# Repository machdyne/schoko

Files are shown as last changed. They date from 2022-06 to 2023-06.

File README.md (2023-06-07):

# Schoko Computer

Schoko is an FPGA computer designed by Lone Dynamics Corporation.

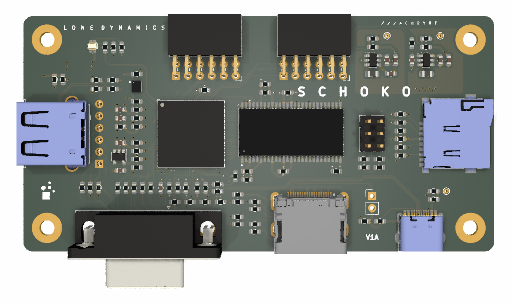
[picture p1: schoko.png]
Schoko Computer


This repo contains schematics, pinouts, a 3D-printable case, example gateware and documentation.

Find more information on the [Schoko product page](https://machdyne.com/product/schoko-computer/).

## Programming Schoko

Schoko has a JTAG interface and ships with a [DFU bootloader](https://github.com/machdyne/tinydfu-bootloader) that allows the included flash [MMOD](https://machdyne.com/product/mmod) to be programmed over the USB-C port.

The first 1MB of the flash MMOD is reserved for the bootloader, the next 3MB are reserved for user gateware and the remaining space is available for user data.

### DFU

The DFU bootloader is available for 5 seconds after power-on, issuing a DFU command during this period will stop the boot process until the DFU device is detached. If no command is received the boot process will continue and the user gateware will be loaded.

Install [dfu-util](http://dfu-util.sourceforge.net) (Debian/Ubuntu):

```
$ sudo apt install dfu-util
```

Update the user gateware on the flash MMOD:

```
$ sudo dfu-util -a 0 -D image.bit
```

Detach the DFU device and continue the boot process:

```
$ sudo dfu-util -a 0 -e
```

It is possible to update the bootloader itself using DFU but you shouldn't attempt this unless you have a JTAG programmer (or another method to program the MMOD) available, in case you need to restore the bootloader.

### JTAG

These examples assume you're using a "USB Blaster" JTAG cable, see the header pinout below. You will need to have [openFPGALoader](https://github.com/trabucayre/openFPGALoader) installed.

Program the configuration SRAM:

```
openFPGALoader -c usb-blaster image.bit
```

Program the flash MMOD:

```
openFPGALoader -f -c usb-blaster images/bootloader/tinydfu_schoko.bit
```

## Blinky 

Building the blinky example requires [Yosys](https://github.com/YosysHQ/yosys), [nextpnr-ecp5](https://github.com/YosysHQ/nextpnr) and [Project Trellis](https://github.com/YosysHQ/prjtrellis).

Assuming they are installed, you can simply type `make` to build the gateware, which will be written to output/blinky.bin. You can then use [openFPGALoader](https://github.com/trabucayre/openFPGALoader) or dfu-util to write the gateware to the device.

## Linux

See the [Kakao Linux](https://github.com/machdyne/kakao) repo for the latest instructions.

### Prebuilt Images

Copy the files from the `images/linux` directory to the root directory of a FAT-formatted MicroSD card.

Schoko ships with LiteX gateware on the user gateware section of the MMOD that is compatible with these images. If you plug a USB-UART into PMODA you should be able to interact with LiteX and view the Linux boot messages. After several seconds the Linux penguin should appear on the screen (HDMI) followed by a login prompt.

You can switch to the VGA gateware with:
 
```
$ sudo dfu-util -a 0 -D images/v1_vga/schoko.bit
```

Note: It should be possible to store the Linux images on the MMOD itself and boot Linux without any MicroSD card but this is not yet supported.

### Building Linux

Please follow the setup instructions in the [linux-on-litex-vexriscv](https://github.com/litex-hub/linux-on-litex-vexriscv) repo and then:

1. Build the Linux-capable gateware:

```
$ cd linux-on-litex-vexriscv
$ ./make.py --board schoko --uart-baudrate 1000000 --build
$ ls build/schoko
```

2. Write the gateware to the MMOD using USB DFU:

```
$ sudo dfu-util -a 0 -D build/schoko/gateware/schoko.bit
```

3. Copy the device tree binary `build/schoko/schoko.dtb` to a FAT-formatted MicroSD card.

4. Build the Linux kernel and root filesystem:

```
$ cd ..
$ git clone http://github.com/buildroot/buildroot
$ cd buildroot
$ make BR2_EXTERNAL=../linux-on-litex-vexriscv/buildroot/ litex_vexriscv_usbhost_defconfig
```

Optionally customize the kernel and buildroot packages:

```
$ make menuconfig
```

Build the kernel and rootfs:

```
$ make
$ ls output/images
```

5. Copy the `Image` and `rootfs.cpio` files from output/images to the MicroSD card.

6. Copy the OpenSBI binary (included in this repo as `schoko/images/linux/opensbi.bin`) to the MicroSD card. Alternatively, you can build this binary by following [these instructions](https://github.com/litex-hub/linux-on-litex-vexriscv#-generating-the-opensbi-binary-optional).

7. Copy `schoko/images/linux/boot.json` to the MicroSD card.

8. Power-cycle Schoko and if a USB-UART PMOD is attached to PMODA you should see the LiteX memory test and then the Linux boot messages. After Linux has finished booting you should see a login prompt on the serial console and the HDMI display.

## LiteX

### Installing LiteX

If you haven't yet installed LiteX please see the [LiteX quick start guide](https://github.com/enjoy-digital/litex#quick-start-guide) for details on installing LiteX.

### Building Custom Gateware

Build the LiteX gateware:

```
$ cd litex-boards/litex_boards/targets
$ ./machdyne_schoko.py --cpu-type=vexriscv --cpu-variant=lite --sys-clk-freq 40000000 --uart-baudrate 1000000 --uart-name serial --build
```

Program the LiteX gateware to SRAM over JTAG:

```
$ ./machdyne_schoko.py --cable usb-blaster --load
```

Or program the LiteX gateware to flash over DFU:

```
$ sudo dfu-util -a 0 -D build/machdyne_schoko/gateware/machdyne_schoko.bit
```

## JTAG Header

The JTAG header can be used to program the FPGA SRAM as well as the MMOD flash memory. 

```
1 2
3 4
5 6
```

| Pin | Signal |
| --- | --- |
| 1 | TCK |
| 2 | TDI |
| 3 | TDO |
| 4 | TMS |
| 5 | 3V3 |
| 6 | GND |

## Board Revisions

| Revision | Notes |
| --- | ----- |
| V0 | Internal prototype |
| V1 | Initial production boards |
| V1A | Identical to V1 except for minor aesthetic changes on the silkscreen |
| V2 | Work-in-progress; adds SD-mode for MicroSD card |

## License

The contents of this repo are released under the [Lone Dynamics Open License](LICENSE.md) with the following exceptions:

- The KiCad design files contain parts of the [kicad-pmod](https://github.com/mithro/kicad-pmod) library which is released under the [Apache License, Version 2.0](https://www.apache.org/licenses/LICENSE-2.0.html).

- The KiCad design files may contain symbols and footprints released under other licenses; please contact us if we've failed to give proper attribution.

Note: You can use these designs for commercial purposes but we ask that instead of producing exact clones, that you either replace our trademarks and logos with your own or add your own next to ours.

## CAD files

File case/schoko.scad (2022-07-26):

/*
 * Schoko Case
 * Copyright (c) 2022 Lone Dynamics Corporation. All rights reserved.
 *
 */

$fn = 100;

mach_edition = false;
schoko_text = true;

board_width = 50;
board_thickness = 1.5;
board_length = 100;
board_height = 20;
board_spacing = 2;

ldx_board();

translate([0,0,15])
	ldx_case_top();

translate([0,0,-15])
	ldx_case_bottom();

module ldx_board() {
	
	difference() {
		color([0,0.5,0])
			roundedcube(board_width,board_length,board_thickness,3);
		translate([5, 5, -1]) cylinder(d=3.2, h=10);
		translate([5, 95, -1]) cylinder(d=3.2, h=10);
		translate([45, 5, -1]) cylinder(d=3.2, h=10);
		translate([45, 95, -1]) cylinder(d=3.2, h=10);
	}	
	
}

module ldx_case_top() {

	union() {
	
		// support between pmods
		translate([0,50-3.5,0])
				cube([5,7.5,14.5]);

		// support above usb host port
		if (mach_edition) {
			translate([25-(14.5/2),-1,7.5]) cube([14.5,10,8.5]);
		} else {
			translate([25-(14.5/2),0,7.5]) cube([14.5,10,7.5]);
		}
		
		difference() {

			union () {
			
				color([0.5,0.5,0.5])
					roundedcube(board_width,board_length,15,3);

				if (mach_edition) {
					translate([-1,board_length-15+1,6])
						cube([board_width+2,4,10]);
					translate([-1,board_length-20+1,6])
						cube([board_width+2,4,10]);
					translate([-1,board_length-25+1,6])
						cube([board_width+2,4,10]);
				}
			
			}
	
			translate([1.5,2,-2.8])
				roundedcube(board_width-3,board_length-4,6,3);

			translate([1.5,10,-2])
				roundedcube(board_width-8,board_length-63.7,15,3);

			translate([10.5,2,-2])
				roundedcube(board_width-21.5,board_length-4,15,5);

			// vent
			translate([-1,board_length-15,10])
				cube([(board_width/2)-8,1,8]);		
			translate([(board_width/2)+8,board_length-15,10])
				cube([(board_width/2)-8,1,8]);

			translate([-1,board_length-20,10])
				cube([(board_width/2)-8,1,8]);		
			translate([(board_width/2)+8,board_length-20,10])
				cube([(board_width/2)-8,1,8]);

			if (!mach_edition) {

				translate([-1,board_length-25,10])
					cube([(board_width/2)-8,1,8]);		
				translate([(board_width/2)+8,board_length-25,10])
					cube([(board_width/2)-8,1,8]);
			
			}

			// LED vent
			translate([-1,board_length-80,5])
				cube([board_width-10,2,2]);

			translate([-1,board_length-85,5])
				cube([board_width-10,2,2]);

			translate([-1,board_length-90,5])
				cube([board_width-10,2,2]);
		
			// VGA
			translate([30,26.23-(31/2),-2]) cube([30,31,12.5+2]);

			// DDMI
			translate([30,60.8-(16/2),-2]) cube([30,15.5,6+2]);

			// USBC
			translate([30,84.3-(10.5/2),-2]) cube([30,10,3.5+1.75]);

			// USBA HOST
			translate([25-(14.5/2),-2,-2]) cube([14.5,30,7.5+2]);
		
			// SD
			translate([25-(15/2),90,-2]) cube([15,30,2+2]);

			// SD resistor cutouts
			translate([8,74,-2]) cube([15,10,2+2]);
			translate([17,74,-2]) cube([15,10,2+2]);

			// PMODA
			translate([0,45.095-(13.05/2),0]) cube([25,16,10],center=true);

			// PMODB
			translate([0,67.955-(13.05/2),0]) cube([25,16,10], center=true);
		
			// bolt holes
			translate([5, 5, -21]) cylinder(d=3.5, h=40);
			translate([5, 95, -21]) cylinder(d=3.5, h=40);
			translate([45, 5, -20]) cylinder(d=3.5, h=40);
			translate([45, 95, -21]) cylinder(d=3.5, h=40);

			// flush mount bolt holes
			translate([5, 5, 14]) cylinder(d=5, h=4);
			translate([5, 95, 14]) cylinder(d=5, h=4);
			translate([45, 5, 14]) cylinder(d=5, h=4);
			translate([45, 95, 14]) cylinder(d=5, h=4);

			// schoko text
			if (schoko_text) {
				rotate(270)
					translate([-40,25-3,14])
						linear_extrude(5)
							text("S C H O K O", size=6, halign="center",
								font="Ubuntu:style=Bold");
			}

		}	
	
	}

}

module ldx_case_bottom() {
	
	difference() {
		color([0.5,0.5,0.5])
			roundedcube(board_width,board_length,8.5,3);
		
		translate([2,10,2])
			roundedcube(board_width-4,board_length-20,8,3);
				
		translate([10,2.5,2])
			roundedcube(board_width-20,board_length-5,8,3);

		// bolt holes
		translate([5, 5, -11]) cylinder(d=3.2, h=25);
		translate([5, 95, -11]) cylinder(d=3.2, h=25);
		translate([45, 5, -11]) cylinder(d=3.2, h=25);
		translate([45, 95, -11]) cylinder(d=3.2, h=25);

		// nut holes
		translate([5, 5, -1.5]) cylinder(d=7, h=4.5, $fn=6);
		translate([5, 95, -1.5]) cylinder(d=7, h=4.5, $fn=6);
		translate([45, 5, -1.5]) cylinder(d=7, h=4.5, $fn=6);
		translate([45, 95, -1.5]) cylinder(d=7, h=4.5, $fn=6);

	}	
}

// https://gist.github.com/tinkerology/ae257c5340a33ee2f149ff3ae97d9826
module roundedcube(xx, yy, height, radius)
{
    translate([0,0,height/2])
    hull()
    {
        translate([radius,radius,0])
        cylinder(height,radius,radius,true);

        translate([xx-radius,radius,0])
        cylinder(height,radius,radius,true);

        translate([xx-radius,yy-radius,0])
        cylinder(height,radius,radius,true);

        translate([radius,yy-radius,0])
        cylinder(height,radius,radius,true);
    }
}

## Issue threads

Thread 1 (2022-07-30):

Source code for the VGA bit stream

wdevore, 2022-07-30:
Is the HDL source code available and more importantly a complete PCF file? Thanks.

machdyne, 2022-07-30:
I've updated the [schoko_v1.lpf](https://github.com/machdyne/schoko/blob/main/schoko_v1.lpf) file, it should now be complete. It was partially generated by LiteX from this file:

[litex_boards/platforms/machdyne_schoko.py](https://github.com/litex-hub/litex-boards/blob/master/litex_boards/platforms/machdyne_schoko.py)

The `images/v1_vga/schoko.bit` bitstream was generated by [linux-on-litex-vexriscv](https://github.com/litex-hub/linux-on-litex-vexriscv) after enabling the "VGA Framebuffer" and disabling the "DDMI Framebuffer" section in this file:

[litex_boards/targets/machdyne_schoko.py](https://github.com/litex-hub/litex-boards/blob/master/litex_boards/targets/machdyne_schoko.py)

If you want to customize/build the bitstream yourself there are some instructions for [Building Linux](https://github.com/machdyne/schoko#building-linux).

There's also [instructions for using LiteX](https://github.com/machdyne/schoko#litex) to build simpler gateware if you don't want to run Linux but still want the LiteX CPUs, SDRAM controller, framebuffer, etc.

We don't have any non-LiteX examples so far beyond the blinky in this repo.

wdevore, 2022-07-30:
Okay, cool. I'll checkout the .lpf file, although I'm not that familiar with .lpf files. How similar are they to .pcf?

machdyne, 2022-07-30:
The purpose is similar but LPF has different syntax and options for ECP5.

There's bit more detail here:

https://github.com/YosysHQ/nextpnr/blob/master/docs/constraints.md

wdevore, 2022-07-30:
Excellent, thanks.

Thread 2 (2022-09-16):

About the USB host

regymm, 2022-09-16:
Hi, the board looks interesting!

I'm curious how does the USB host work? For the other USB port, it seems a USB device is implemented in FPGA fabric(as in the DFU repo), but I didn't find any explanation about the USB host. Is there any demo code or so here or on Litex?

machdyne, 2022-09-16:
Hi. The USB host controller is also implemented in FPGA fabric.

There is a USB OHCI included in LiteX as [usb_ohci.py](https://github.com/enjoy-digital/litex/blob/master/litex/soc/cores/usb_ohci.py) that is [from SpinalHDL](https://spinalhdl.github.io/SpinalDoc-RTD/dev/SpinalHDL/Libraries/Com/usb_ohci.html).

You can see where it's used by Schoko [here](https://github.com/litex-hub/litex-boards/blob/master/litex_boards/targets/machdyne_schoko.py#L132).

USB host support is automatically enabled when building [linux-on-litex-riscv](https://github.com/litex-hub/linux-on-litex-vexriscv) for Schoko.

I've successfully tested a USB keyboard, USB ethernet and USB flash drives with Schoko from Linux.

There does seem to be some issues when using multiple devices through the USB hubs that I've tried. I haven't been able to debug that yet but hopefully it will be resolved eventually.

regymm, 2022-09-16:
Thanks for your quick reply. It's amazing to see USB host works well on 2 wires.

Closed 2022-09-16.

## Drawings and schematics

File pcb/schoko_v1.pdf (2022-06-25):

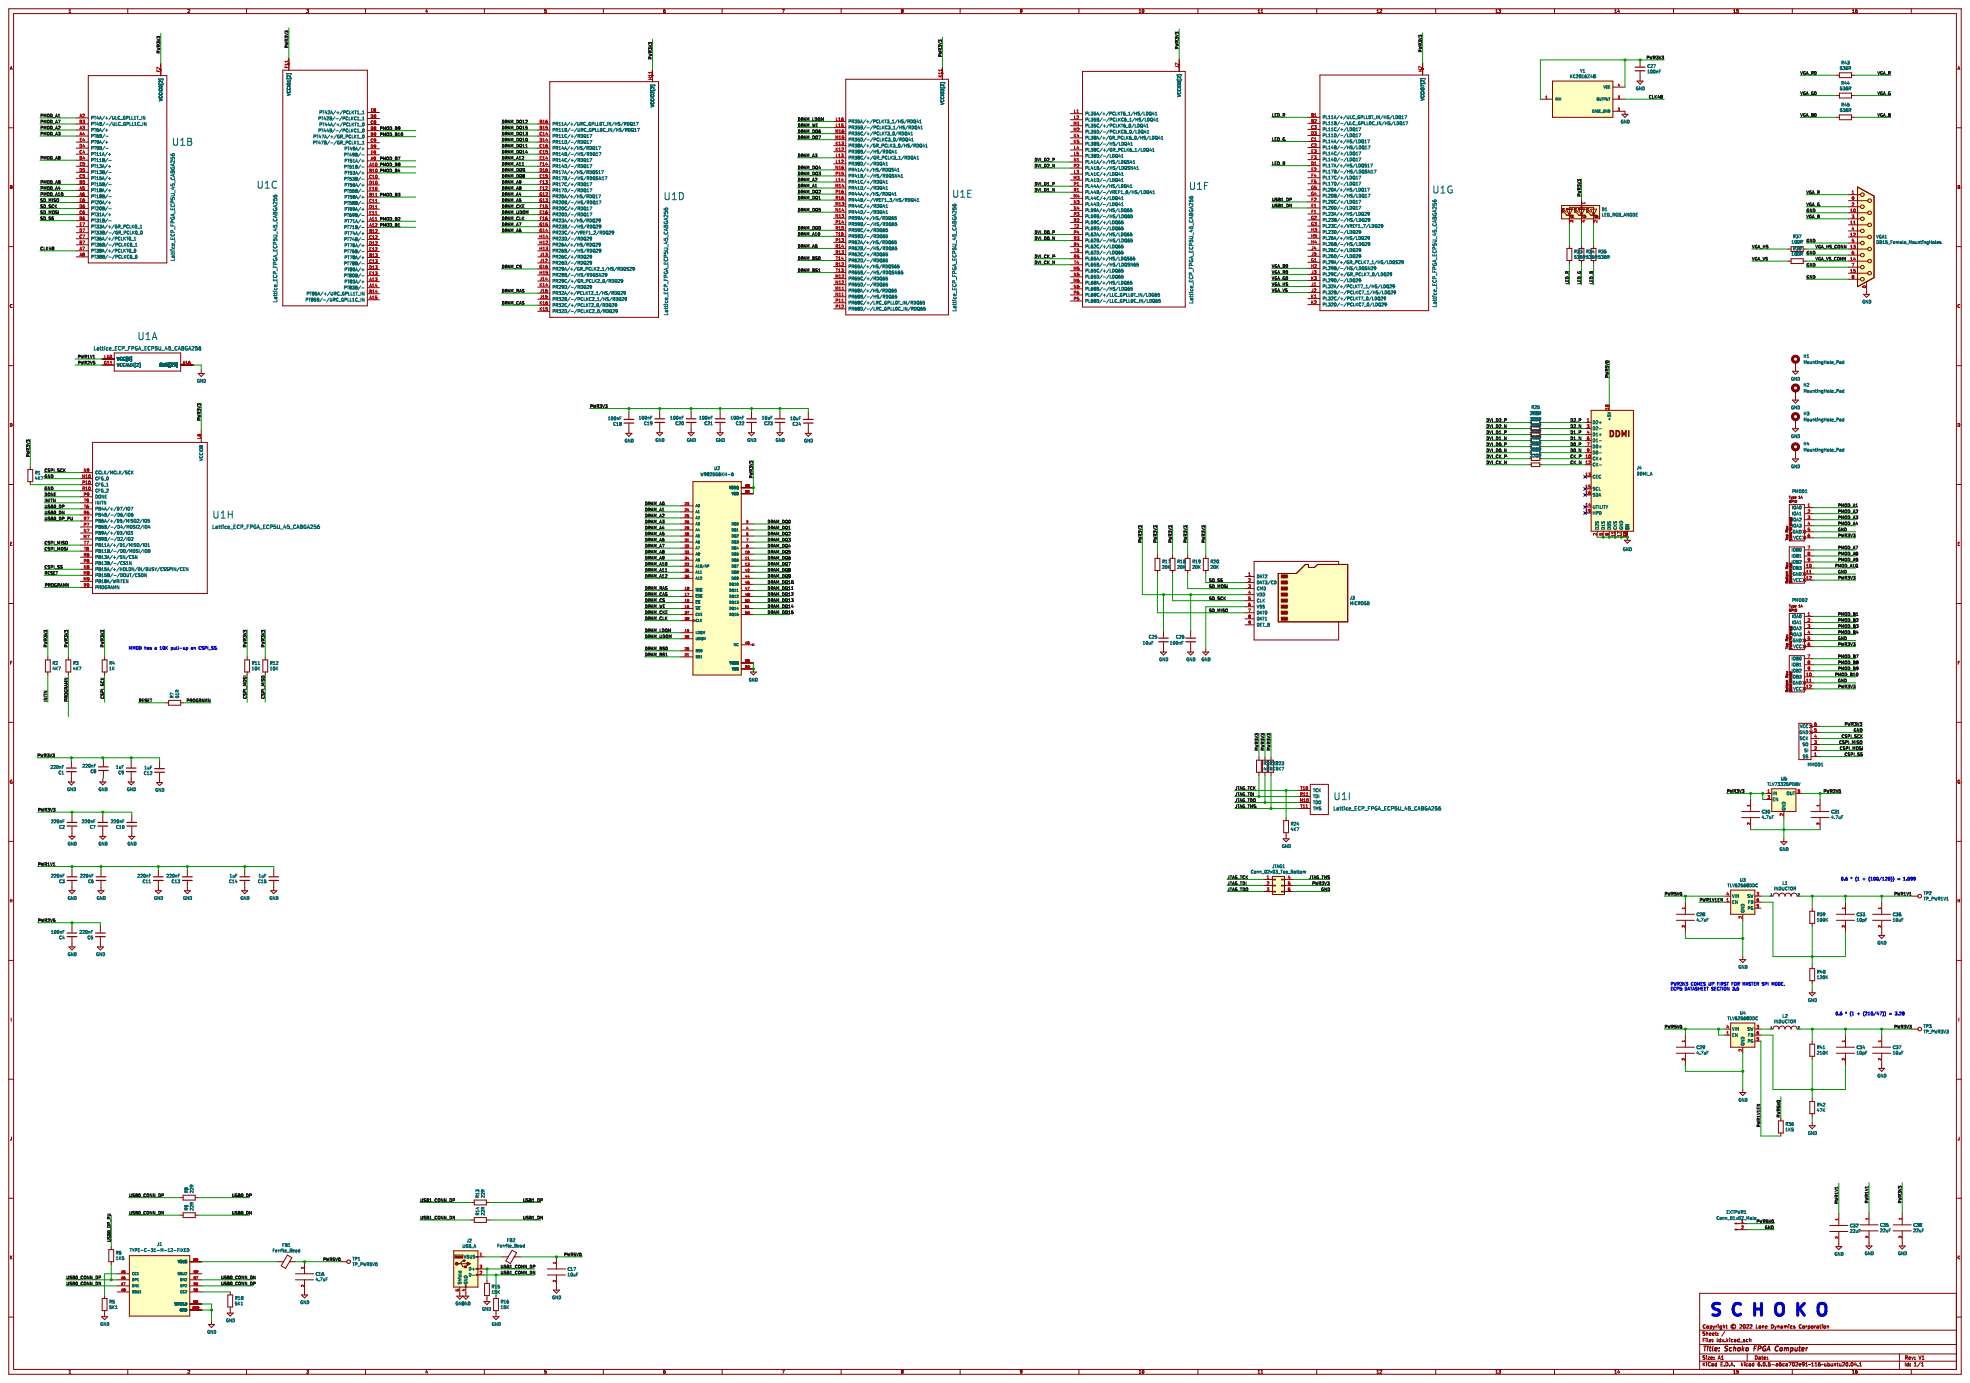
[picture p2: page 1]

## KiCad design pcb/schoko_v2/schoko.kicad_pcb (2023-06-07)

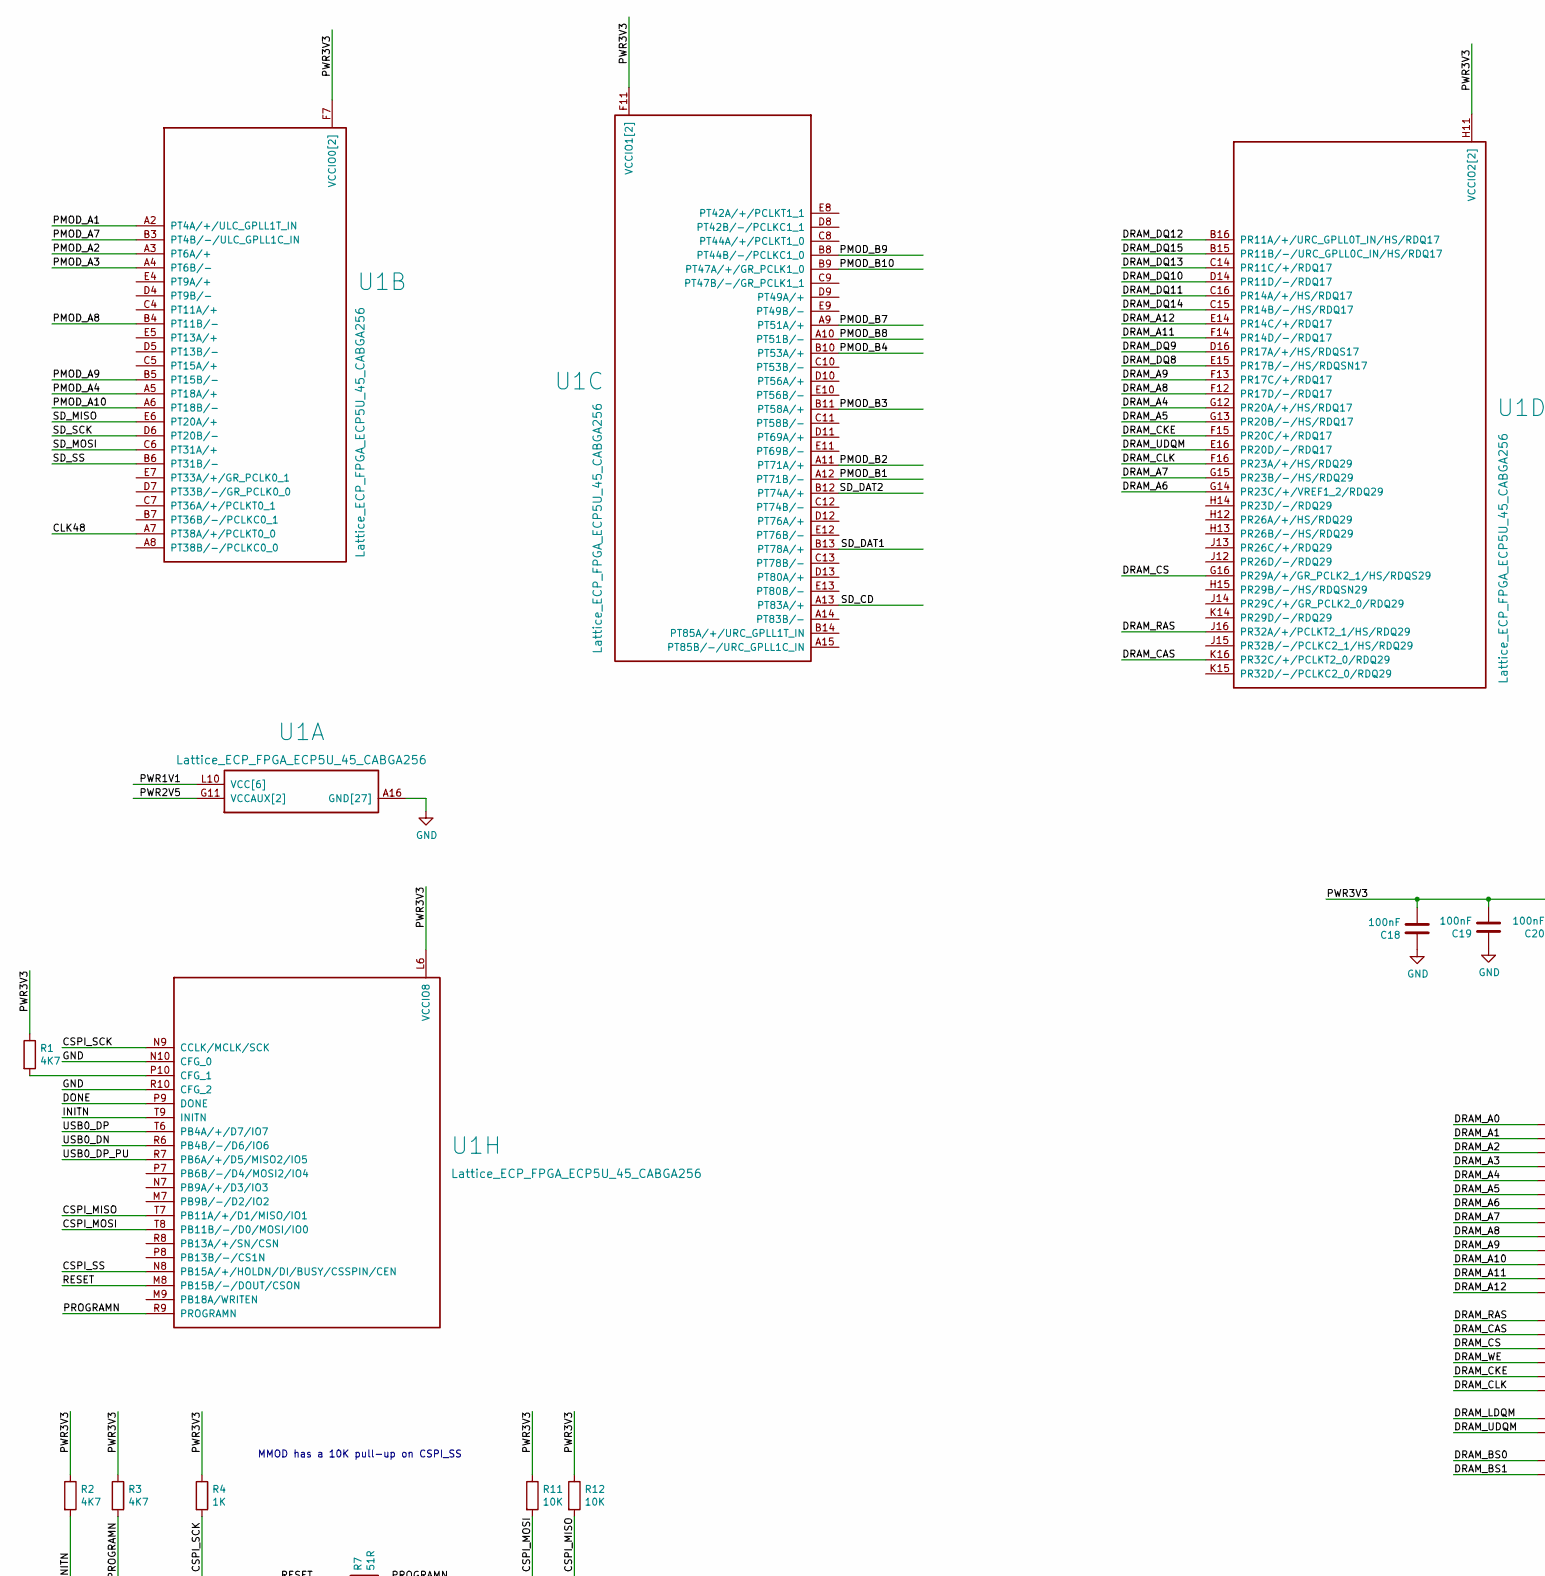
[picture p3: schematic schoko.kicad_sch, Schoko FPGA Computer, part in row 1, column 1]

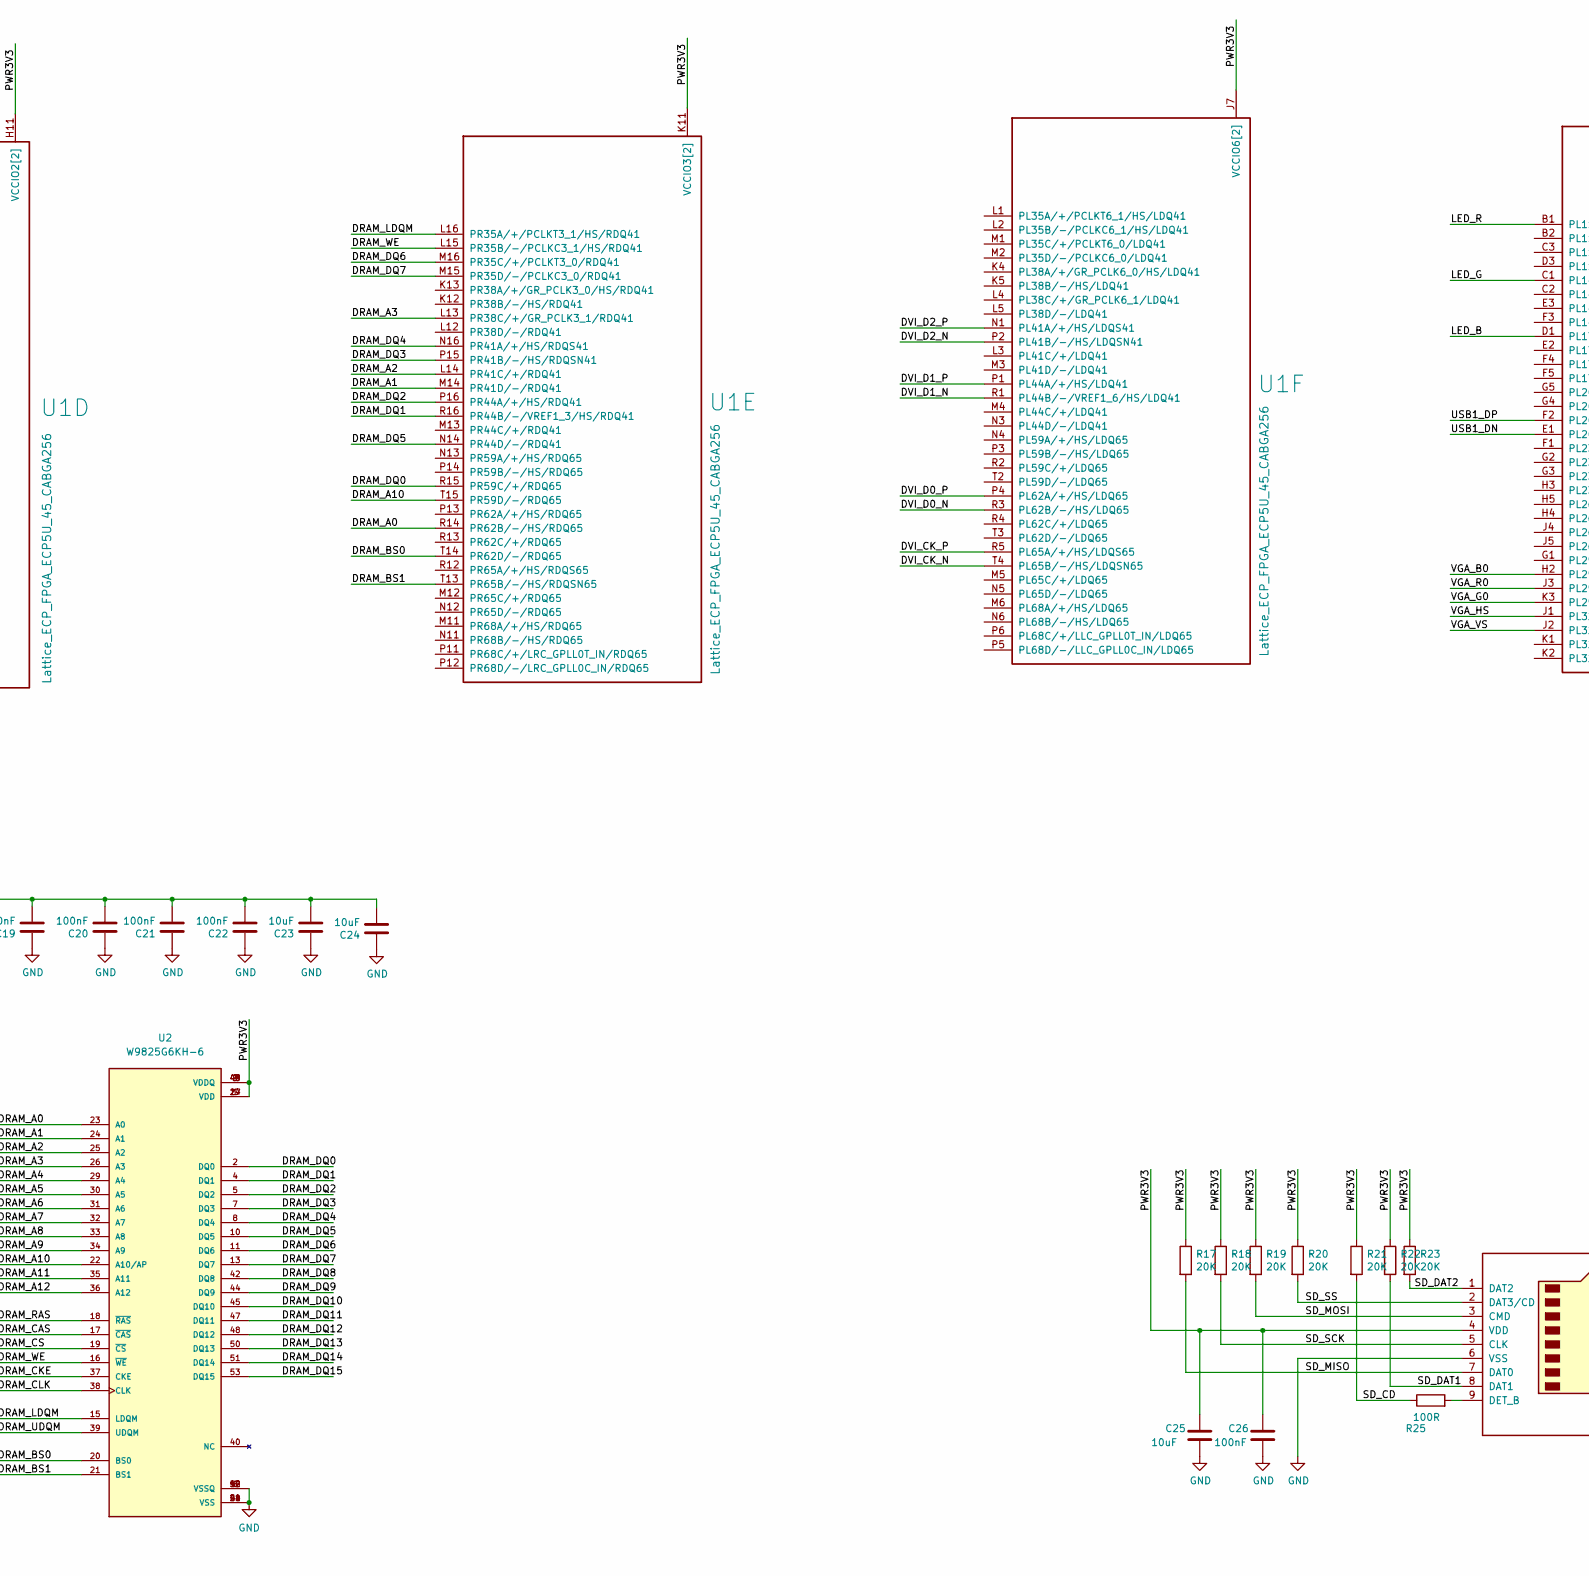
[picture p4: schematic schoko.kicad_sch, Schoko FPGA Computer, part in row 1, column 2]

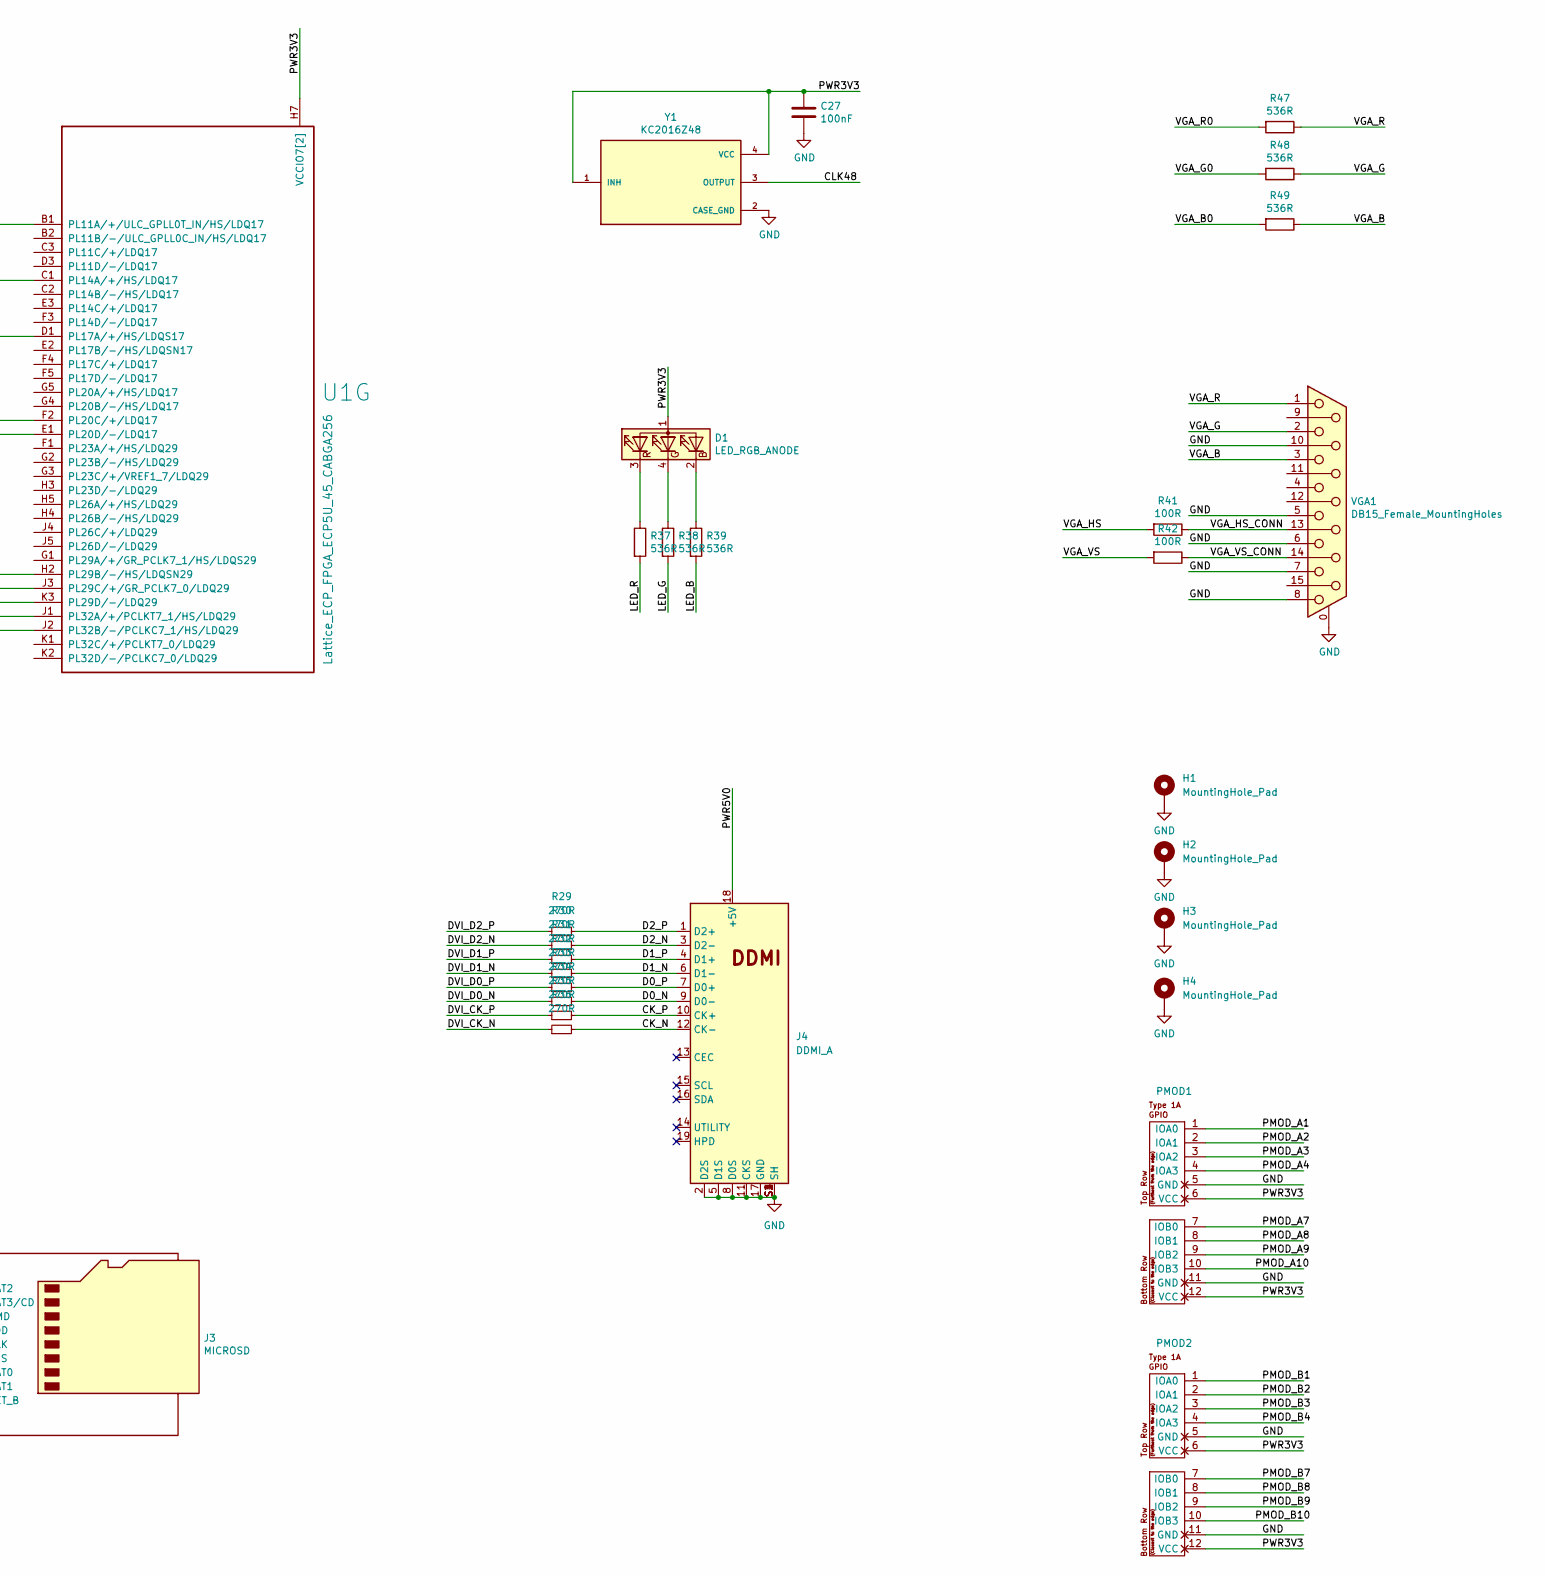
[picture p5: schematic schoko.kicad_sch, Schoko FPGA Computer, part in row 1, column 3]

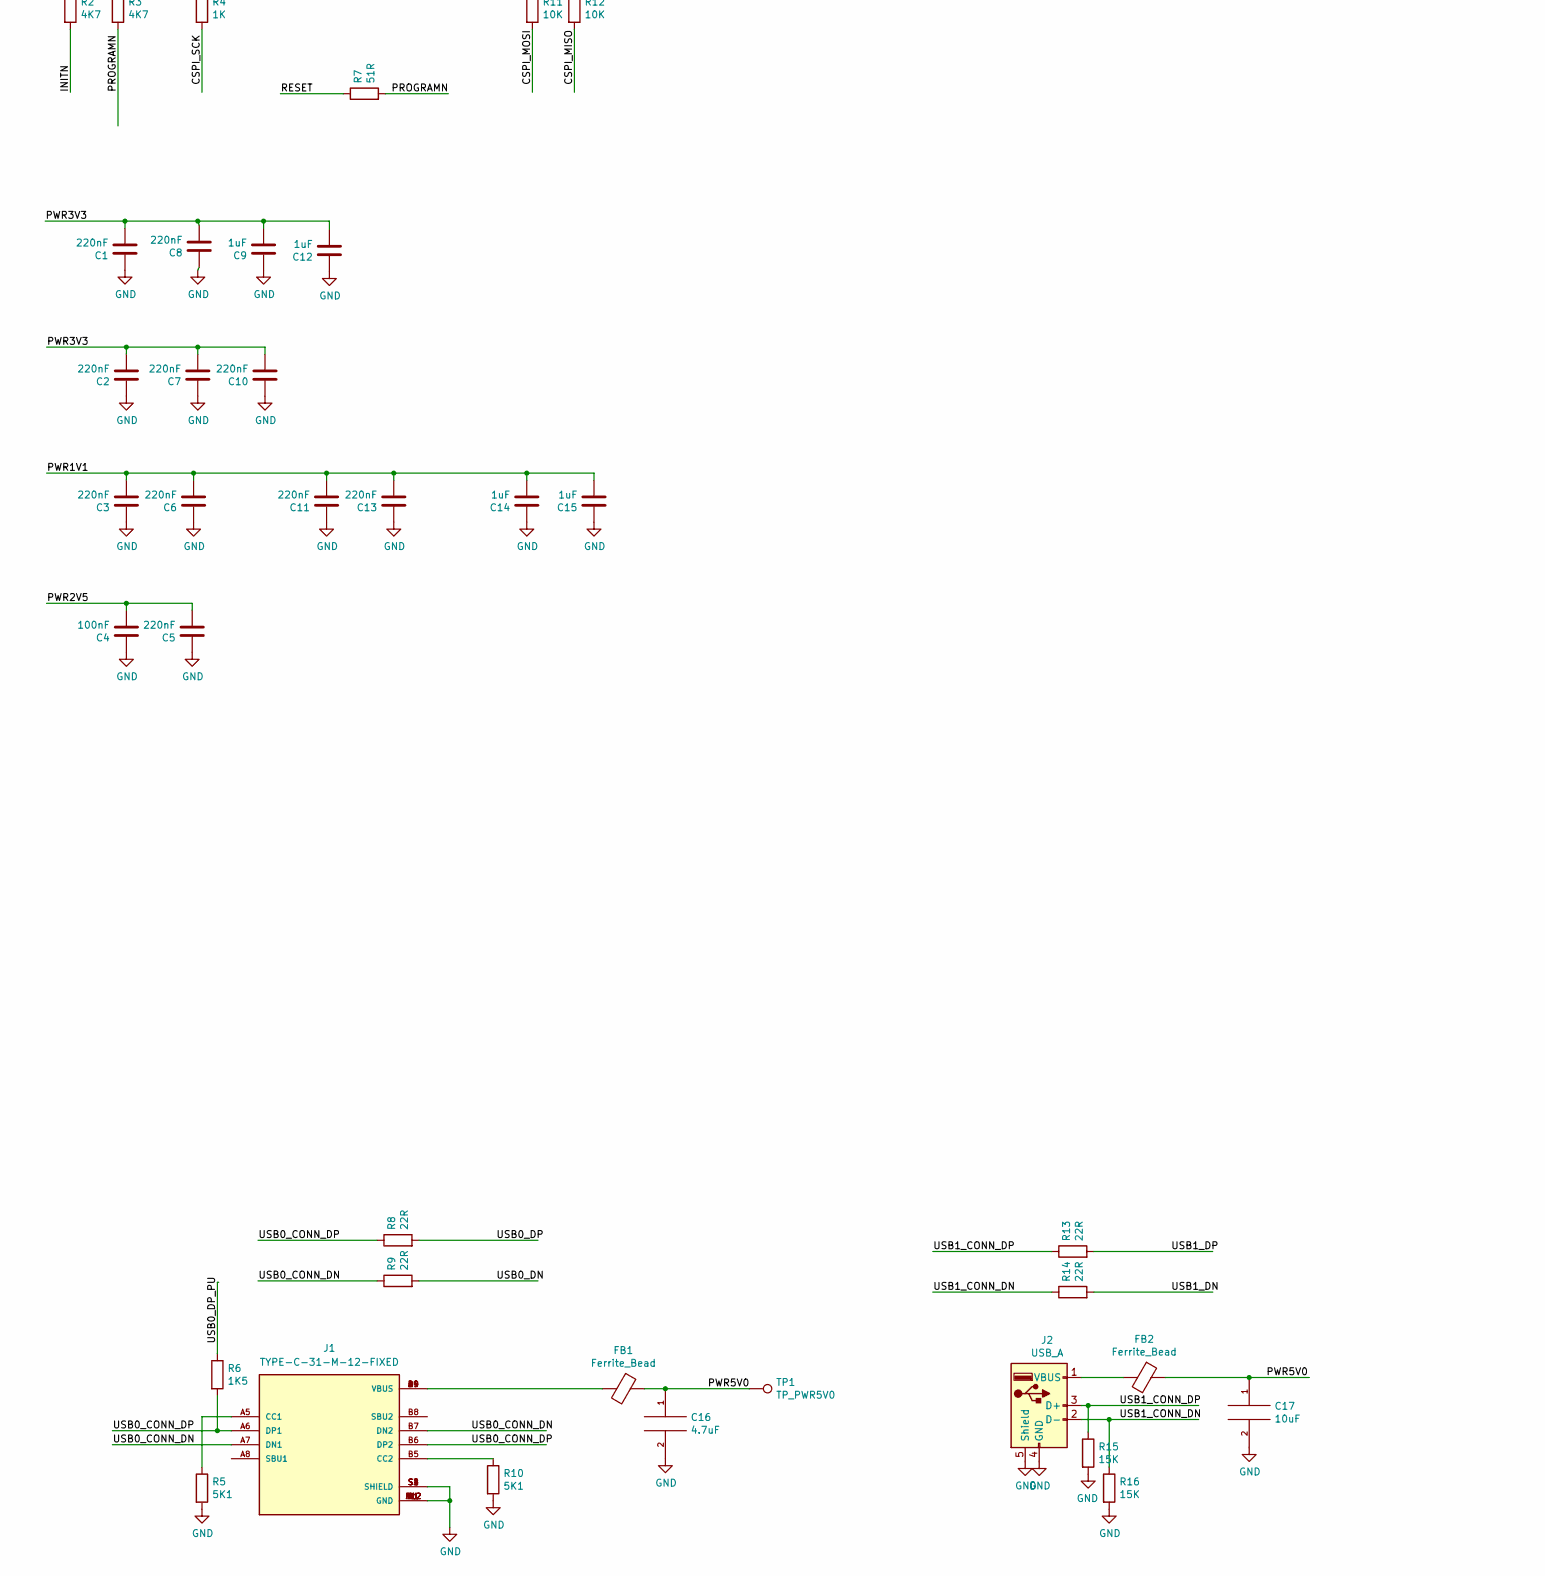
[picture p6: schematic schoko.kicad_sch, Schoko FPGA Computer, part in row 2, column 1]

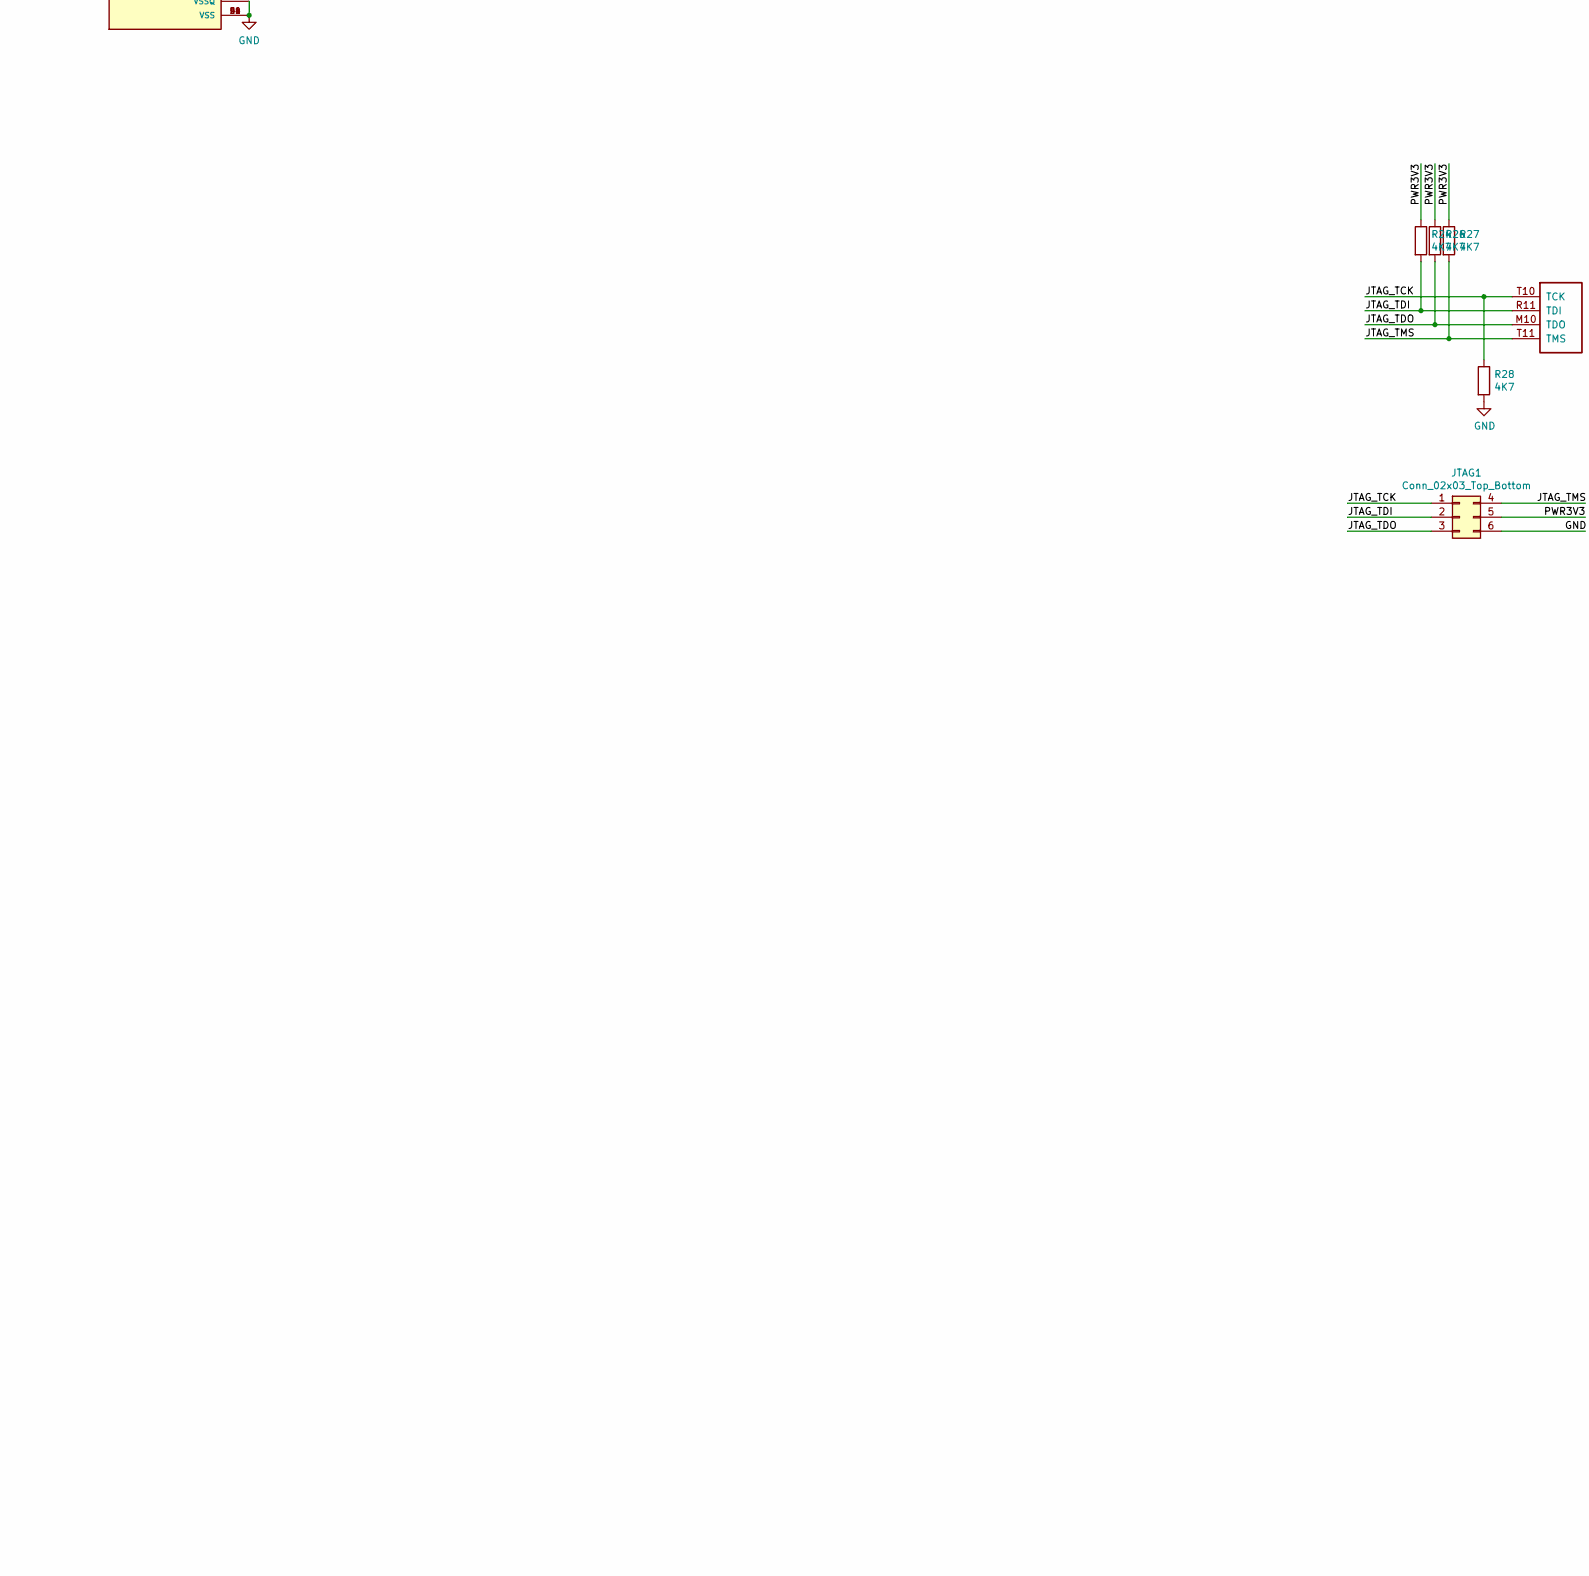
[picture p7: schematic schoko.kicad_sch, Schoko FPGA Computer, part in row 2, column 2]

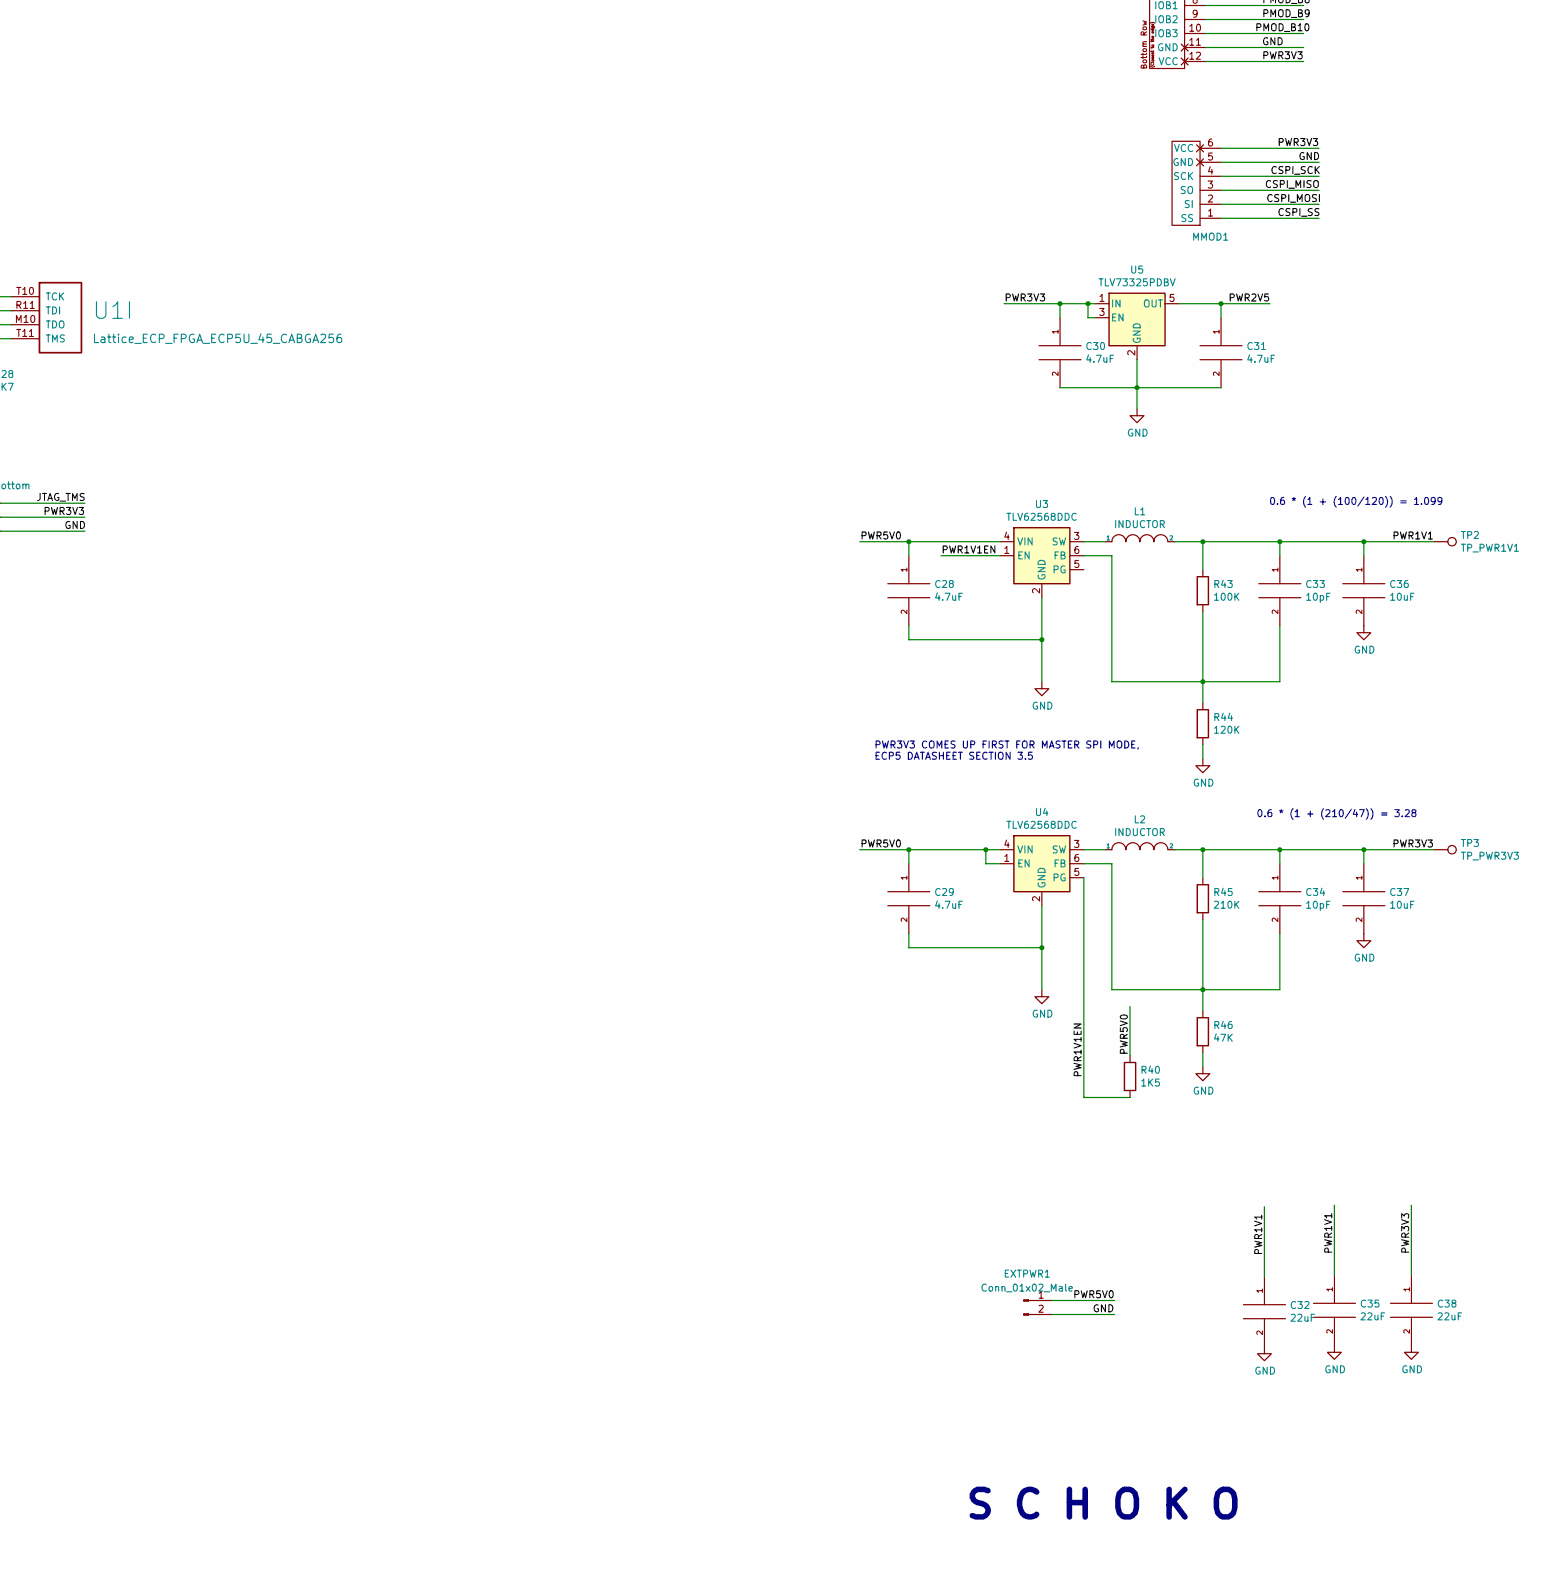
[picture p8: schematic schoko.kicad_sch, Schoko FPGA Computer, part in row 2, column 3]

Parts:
C1, C2, C3, C5, C6, C7, C8, C10, C11, C13: 220nF; R_0603_1608Metric
C4, C18, C19, C20, C21, C22, C26, C27: 100nF; R_0603_1608Metric
C9, C12, C14, C15: 1uF; R_0603_1608Metric
C16: 4.7uF; R_0603_1608Metric
C17, C23, C24, C25: 10uF; R_0603_1608Metric
C28, C29, C30, C31: 4.7uF; C_0603_1608Metric
C32, C35, C38: 22uF; C_0603_1608Metric
C33, C34: 10pF; C_0603_1608Metric
C36, C37: 10uF; C_0603_1608Metric
D1: LED_RGB_ANODE; LED_RGB_0606_CHANZON
EXTPWR1: Conn_01x02_Male; PinHeader_1x02_P2.54mm_Vertical
FB1, FB2: Ferrite_Bead; R_0603_1608Metric
H1, H2, H3, H4: MountingHole_Pad; MountingHole_3.2mm_M3_Pad
J1: TYPE-C-31-M-12-FIXED; USB_C_Receptacle_HRO_TYPE-C-31-M-12-BIG-PADS; PARTREV A
J2: USB_A; USB_A_Stewart_SS-52100-001_Horizontal
J3: MICROSD; SDCARD
J4: DDMI_A; HDMI_TE_1827059-3-FIXED
JTAG1: Conn_02x03_Top_Bottom; PinHeader_2x03_P2.54mm_Vertical
L1, L2: INDUCTOR; L_0805_2012Metric
MMOD1: PMOD-Device-x1-Type-2-SPI; MMOD_Host_Socket
PMOD1, PMOD2: PMOD-Device-x2-Type-1A-GPIO; PMOD_2x06_HOST
R1, R2, R3, R24, R26, R27, R28: 4K7; R_0603_1608Metric
R4: 1K; R_0603_1608Metric
R5, R10: 5K1; R_0603_1608Metric
R6, R40: 1K5; R_0603_1608Metric
R7: 51R; R_0603_1608Metric
R8, R9, R13, R14: 22R; R_0603_1608Metric
R11, R12: 10K; R_0603_1608Metric
R15, R16: 15K; R_0603_1608Metric
R17, R18, R19, R20, R21, R22, R23: 20K; R_0603_1608Metric
R25, R41, R42: 100R; R_0603_1608Metric
R29, R30, R31, R32, R33, R34, R35, R36: 270R; R_0603_1608Metric
R37, R38, R39, R47, R48, R49: 536R; R_0603_1608Metric
R43: 100K; R_0603_1608Metric
R44: 120K; R_0603_1608Metric
R45: 210K; R_0603_1608Metric
R46: 47K; R_0603_1608Metric
TP1: TP_PWR5V0; TestPoint_THTPad_D1.0mm_Drill0.5mm
TP2: TP_PWR1V1; TestPoint_THTPad_D1.0mm_Drill0.5mm
TP3: TP_PWR3V3; TestPoint_THTPad_D1.0mm_Drill0.5mm
U1: Lattice_ECP_FPGA_ECP5U_45_CABGA256; BGA-256_14.0x14.0mm_Layout16x16_P0.8mm_Ball0.45mm_Pad0.32mm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
U2: W9825G6KH-6; SOP80P1176X120-54N; PARTREV A05
U3, U4: TLV62568DDC; SOT-23-6
U5: TLV73325PDBV; SOT-23-5
VGA1: DB15_Female_MountingHoles; DSUB-15-HD_Female_Horizontal_P2.29x1.98mm_EdgePinOffset3.03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
Y1: KC2016Z48; OSC_KC2016Z13.5600C1KX00; PARTREV November 2020

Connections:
/CK_N: J4.12 (CK-), R36.2
/CK_P: J4.10 (CK+), R35.2
/CLK48: U1.A7 (PT38A/+/PCLKT0_0), Y1.3 (OUTPUT)
/CSPI_MISO: MMOD1.3 (SO), R12.2, U1.T7 (PB11A/+/D1/MISO/IO1)
/CSPI_MOSI: MMOD1.2 (SI), R11.2, U1.T8 (PB11B/-/D0/MOSI/IO0)
/CSPI_SCK: MMOD1.4 (SCK), R4.2, U1.N9 (CCLK/MCLK/SCK)
/CSPI_SS: MMOD1.1 (SS), U1.N8 (PB15A/+/HOLDN/DI/BUSY/CSSPIN/CEN)
/D0_N: J4.9 (D0-), R34.2
/D0_P: J4.7 (D0+), R33.2
/D1_N: J4.6 (D1-), R32.2
/D1_P: J4.4 (D1+), R31.2
/D2_N: J4.3 (D2-), R30.2
/D2_P: J4.1 (D2+), R29.2
/DONE: U1.P9 (DONE)
/DRAM_A0: U1.R14 (PR62B/-/HS/RDQ65), U2.23 (A0)
/DRAM_A1: U1.M14 (PR41D/-/RDQ41), U2.24 (A1)
/DRAM_A2: U1.L14 (PR41C/+/RDQ41), U2.25 (A2)
/DRAM_A3: U1.L13 (PR38C/+/GR_PCLK3_1/RDQ41), U2.26 (A3)
/DRAM_A4: U1.G12 (PR20A/+/HS/RDQ17), U2.29 (A4)
/DRAM_A5: U1.G13 (PR20B/-/HS/RDQ17), U2.30 (A5)
/DRAM_A6: U1.G14 (PR23C/+/VREF1_2/RDQ29), U2.31 (A6)
/DRAM_A7: U1.G15 (PR23B/-/HS/RDQ29), U2.32 (A7)
/DRAM_A8: U1.F12 (PR17D/-/RDQ17), U2.33 (A8)
/DRAM_A9: U1.F13 (PR17C/+/RDQ17), U2.34 (A9)
/DRAM_A10: U1.T15 (PR59D/-/RDQ65), U2.22 (A10/AP)
/DRAM_A11: U1.F14 (PR14D/-/RDQ17), U2.35 (A11)
/DRAM_A12: U1.E14 (PR14C/+/RDQ17), U2.36 (A12)
/DRAM_BS0: U1.T14 (PR62D/-/RDQ65), U2.20 (BS0)
/DRAM_BS1: U1.T13 (PR65B/-/HS/RDQSN65), U2.21 (BS1)
/DRAM_CAS: U1.K16 (PR32C/+/PCLKT2_0/RDQ29), U2.17 (~CAS)
/DRAM_CKE: U1.F15 (PR20C/+/RDQ17), U2.37 (CKE)
/DRAM_CLK: U1.F16 (PR23A/+/HS/RDQ29), U2.38 (CLK)
/DRAM_CS: U1.G16 (PR29A/+/GR_PCLK2_1/HS/RDQS29), U2.19 (~CS)
/DRAM_DQ0: U1.R15 (PR59C/+/RDQ65), U2.2 (DQ0)
/DRAM_DQ1: U1.R16 (PR44B/-/VREF1_3/HS/RDQ41), U2.4 (DQ1)
/DRAM_DQ2: U1.P16 (PR44A/+/HS/RDQ41), U2.5 (DQ2)
/DRAM_DQ3: U1.P15 (PR41B/-/HS/RDQSN41), U2.7 (DQ3)
/DRAM_DQ4: U1.N16 (PR41A/+/HS/RDQS41), U2.8 (DQ4)
/DRAM_DQ5: U1.N14 (PR44D/-/RDQ41), U2.10 (DQ5)
/DRAM_DQ6: U1.M16 (PR35C/+/PCLKT3_0/RDQ41), U2.11 (DQ6)
/DRAM_DQ7: U1.M15 (PR35D/-/PCLKC3_0/RDQ41), U2.13 (DQ7)
/DRAM_DQ8: U1.E15 (PR17B/-/HS/RDQSN17), U2.42 (DQ8)
/DRAM_DQ9: U1.D16 (PR17A/+/HS/RDQS17), U2.44 (DQ9)
/DRAM_DQ10: U1.D14 (PR11D/-/RDQ17), U2.45 (DQ10)
/DRAM_DQ11: U1.C16 (PR14A/+/HS/RDQ17), U2.47 (DQ11)
/DRAM_DQ12: U1.B16 (PR11A/+/URC_GPLL0T_IN/HS/RDQ17), U2.48 (DQ12)
/DRAM_DQ13: U1.C14 (PR11C/+/RDQ17), U2.50 (DQ13)
/DRAM_DQ14: U1.C15 (PR14B/-/HS/RDQ17), U2.51 (DQ14)
/DRAM_DQ15: U1.B15 (PR11B/-/URC_GPLL0C_IN/HS/RDQ17), U2.53 (DQ15)
/DRAM_LDQM: U1.L16 (PR35A/+/PCLKT3_1/HS/RDQ41), U2.15 (LDQM)
/DRAM_RAS: U1.J16 (PR32A/+/PCLKT2_1/HS/RDQ29), U2.18 (~RAS)
/DRAM_UDQM: U1.E16 (PR20D/-/RDQ17), U2.39 (UDQM)
/DRAM_WE: U1.L15 (PR35B/-/PCLKC3_1/HS/RDQ41), U2.16 (~WE)
/DVI_CK_N: R36.1, U1.T4 (PL65B/-/HS/LDQSN65)
/DVI_CK_P: R35.1, U1.R5 (PL65A/+/HS/LDQS65)
/DVI_D0_N: R34.1, U1.R3 (PL62B/-/HS/LDQ65)
/DVI_D0_P: R33.1, U1.P4 (PL62A/+/HS/LDQ65)
/DVI_D1_N: R32.1, U1.R1 (PL44B/-/VREF1_6/HS/LDQ41)
/DVI_D1_P: R31.1, U1.P1 (PL44A/+/HS/LDQ41)
/DVI_D2_N: R30.1, U1.P2 (PL41B/-/HS/LDQSN41)
/DVI_D2_P: R29.1, U1.N1 (PL41A/+/HS/LDQS41)
/INITN: R2.2, U1.T9 (INITN)
/JTAG_TCK: JTAG1.1, R28.1, U1.T10 (TCK)
/JTAG_TDI: JTAG1.2, R24.2, U1.R11 (TDI)
/JTAG_TDO: JTAG1.3, R26.2, U1.M10 (TDO)
/JTAG_TMS: JTAG1.4, R27.2, U1.T11 (TMS)
/LED_B: R39.2, U1.D1 (PL17A/+/HS/LDQS17)
/LED_G: R38.2, U1.C1 (PL14A/+/HS/LDQ17)
/LED_R: R37.2, U1.B1 (PL11A/+/ULC_GPLL0T_IN/HS/LDQ17)
/PMOD_A1: PMOD1.1 (IOA0), U1.A2 (PT4A/+/ULC_GPLL1T_IN)
/PMOD_A2: PMOD1.2 (IOA1), U1.A3 (PT6A/+)
/PMOD_A3: PMOD1.3 (IOA2), U1.A4 (PT6B/-)
/PMOD_A4: PMOD1.4 (IOA3), U1.A5 (PT18A/+)
/PMOD_A7: PMOD1.7 (IOB0), U1.B3 (PT4B/-/ULC_GPLL1C_IN)
/PMOD_A8: PMOD1.8 (IOB1), U1.B4 (PT11B/-)
/PMOD_A9: PMOD1.9 (IOB2), U1.B5 (PT15B/-)
/PMOD_A10: PMOD1.10 (IOB3), U1.A6 (PT18B/-)
/PMOD_B1: PMOD2.1 (IOA0), U1.A12 (PT71B/-)
/PMOD_B2: PMOD2.2 (IOA1), U1.A11 (PT71A/+)
/PMOD_B3: PMOD2.3 (IOA2), U1.B11 (PT58A/+)
/PMOD_B4: PMOD2.4 (IOA3), U1.B10 (PT53A/+)
/PMOD_B7: PMOD2.7 (IOB0), U1.A9 (PT51A/+)
/PMOD_B8: PMOD2.8 (IOB1), U1.A10 (PT51B/-)
/PMOD_B9: PMOD2.9 (IOB2), U1.B8 (PT44B/-/PCLKC1_0)
/PMOD_B10: PMOD2.10 (IOB3), U1.B9 (PT47A/+/GR_PCLK1_0)
/PROGRAMN: R3.2, R7.2, U1.R9 (PROGRAMN)
/PWR1V1: C3.2, C6.2, C11.2, C13.2, C14.2, C15.2, C32.1, C33.1, C35.1, C36.1, L1.2, R43.1, TP2.1, U1.G6 (VCC[6]), U1.G7 (VCC[6]), U1.G9 (VCC[6]), U1.L8 (VCC[6]), U1.L9 (VCC[6]), U1.L10 (VCC[6])
/PWR1V1EN: R40.2, U3.1 (EN), U4.5 (PG)
/PWR2V5: C4.2, C5.2, C31.1, U1.G11 (VCCAUX[2]), U1.L7 (VCCAUX[2]), U5.5 (OUT)
/PWR3V3: C1.2, C2.2, C7.2, C8.2, C9.2, C10.2, C12.2, C18.2, C19.2, C20.2, C21.2, C22.2, C23.2, C24.2, C25.1, C26.1, C27.1, C30.1, C34.1, C37.1, C38.1, D1.1 (A), J3.4 (VDD), JTAG1.5, L2.2, MMOD1.6 (VCC), PMOD1.6 (VCC), PMOD1.12 (VCC), PMOD2.6 (VCC), PMOD2.12 (VCC), R1.1, R2.1, R3.1, R4.1, R11.1, R12.1, R17.1, R18.1, R19.1, R20.1, R21.1, R22.1, R23.1, R24.1, R26.1, R27.1, R45.1, TP3.1, U1.F6 (VCCIO0[2]), U1.F7 (VCCIO0[2]), U1.F10 (VCCIO1[2]), U1.F11 (VCCIO1[2]), U1.H6 (VCCIO7[2]), U1.H7 (VCCIO7[2]), U1.H11 (VCCIO2[2]), U1.J6 (VCCIO6[2]), U1.J7 (VCCIO6[2]), U1.J11 (VCCIO2[2]), U1.K11 (VCCIO3[2]), U1.L6 (VCCIO8), U1.L11 (VCCIO3[2]), U2.1 (VDD), U2.3 (VDDQ), U2.9 (VDDQ), U2.14 (VDD), U2.27 (VDD), U2.43 (VDDQ), U2.49 (VDDQ), U5.1 (IN), U5.3 (EN), Y1.1 (INH), Y1.4 (VCC)
/PWR5V0: C16.1, C17.1, C28.1, C29.1, EXTPWR1.1, FB1.1, FB2.1, J4.18 (+5V), R40.1, TP1.1, U3.4 (VIN), U4.1 (EN), U4.4 (VIN)
/RESET: R7.1, U1.M8 (PB15B/-/DOUT/CSON)
/SD_CD: R21.2, R25.1, U1.A13 (PT83A/+)
/SD_DAT1: J3.8 (DAT1), R22.2, U1.B13 (PT78A/+)
/SD_DAT2: J3.1 (DAT2), R23.2, U1.B12 (PT74A/+)
/SD_MISO: J3.7 (DAT0), R17.2, U1.E6 (PT20A/+)
/SD_MOSI: J3.3 (CMD), R19.2, U1.C6 (PT31A/+)
/SD_SCK: J3.5 (CLK), R18.2, U1.D6 (PT20B/-)
/SD_SS: J3.2 (DAT3/CD), R20.2, U1.B6 (PT31B/-)
/USB0_CONN_DN: J1.A7 (DN1), J1.B7 (DN2), R9.1
/USB0_CONN_DP: J1.A6 (DP1), J1.B6 (DP2), R6.2, R8.1
/USB0_DN: R9.2, U1.R6 (PB4B/-/D6/IO6)
/USB0_DP: R8.2, U1.T6 (PB4A/+/D7/IO7)
/USB0_DP_PU: R6.1, U1.R7 (PB6A/+/D5/MISO2/IO5)
/USB1_CONN_DN: J2.2 (D-), R14.1, R16.1
/USB1_CONN_DP: J2.3 (D+), R13.1, R15.1
/USB1_DN: R14.2, U1.E1 (PL20D/-/LDQ17)
/USB1_DP: R13.2, U1.F2 (PL20C/+/LDQ17)
/VGA_B: R49.1, VGA1.3
/VGA_B0: R49.2, U1.H2 (PL29B/-/HS/LDQSN29)
/VGA_G: R48.1, VGA1.2
/VGA_G0: R48.2, U1.K3 (PL29D/-/LDQ29)
/VGA_HS: R41.2, U1.J1 (PL32A/+/PCLKT7_1/HS/LDQ29)
/VGA_HS_CONN: R41.1, VGA1.13
/VGA_R: R47.1, VGA1.1
/VGA_R0: R47.2, U1.J3 (PL29C/+/GR_PCLK7_0/LDQ29)
/VGA_VS: R42.2, U1.J2 (PL32B/-/PCLKC7_1/HS/LDQ29)
/VGA_VS_CONN: R42.1, VGA1.14
GND: C1.1, C2.1, C3.1, C4.1, C5.1, C6.1, C7.1, C8.1, C9.1, C10.1, C11.1, C12.1, C13.1, C14.1, C15.1, C16.2, C17.2, C18.1, C19.1, C20.1, C21.1, C22.1, C23.1, C24.1, C25.2, C26.2, C27.2, C28.2, C29.2, C30.2, C31.2, C32.2, C35.2, C36.2, C37.2, C38.2, EXTPWR1.2, H1.1, H2.1, H3.1, H4.1, J1.A1 (GND), J1.A12 (GND), J1.B1 (GND), J1.B12 (GND), J1.S1 (SHIELD), J1.S2 (SHIELD), J1.S3 (SHIELD), J1.S4 (SHIELD), J2.4 (GND), J2.5 (Shield), J3.6 (VSS), J4.2 (D2S), J4.5 (D1S), J4.8 (D0S), J4.11 (CKS), J4.17 (GND), J4.S1 (SH), J4.S2 (SH), J4.S3 (SH), J4.S4 (SH), JTAG1.6, MMOD1.5 (GND), PMOD1.5 (GND), PMOD1.11 (GND), PMOD2.5 (GND), PMOD2.11 (GND), R5.2, R10.2, R15.2, R16.2, R28.2, R44.2, R46.2, U1.A1 (GND[27]), U1.A16 (GND[27]), U1.D2 (GND[27]), U1.D15 (GND[27]), U1.F8 (GND[27]), U1.F9 (GND[27]), U1.G8 (GND[27]), U1.G10 (GND[27]), U1.H1 (GND[27]), U1.H8 (GND[27]), U1.H9 (GND[27]), U1.H10 (GND[27]), U1.H16 (GND[27]), U1.J8 (GND[27]), U1.J9 (GND[27]), U1.J10 (GND[27]), U1.K6 (GND[27]), U1.K7 (GND[27]), U1.K8 (GND[27]), U1.K9 (GND[27]), U1.K10 (GND[27]), U1.N2 (GND[27]), U1.N10 (CFG_0), U1.N15 (GND[27]), U1.R10 (CFG_2), U1.T1 (GND[27]), U1.T5 (GND[27]), U1.T12 (GND[27]), U1.T16 (GND[27]), U2.6 (VSSQ), U2.12 (VSSQ), U2.28 (VSS), U2.41 (VSS), U2.46 (VSSQ), U2.52 (VSSQ), U2.54 (VSS), U3.2 (GND), U4.2 (GND), U5.2 (GND), VGA1.0 (PAD), VGA1.5, VGA1.6, VGA1.7, VGA1.8, VGA1.10, Y1.2 (CASE_GND)
unnamed: C33.2, R43.2, R44.1, U3.6 (FB)
unnamed: C34.2, R45.2, R46.1, U4.6 (FB)
unnamed: D1.2 (BK), R39.1
unnamed: D1.3 (RK), R37.1
unnamed: D1.4 (GK), R38.1
unnamed: FB1.2, J1.A4 (VBUS), J1.A9 (VBUS), J1.B4 (VBUS), J1.B9 (VBUS)
unnamed: FB2.2, J2.1 (VBUS)
unnamed: J1.A5 (CC1), R5.1
unnamed: J1.B5 (CC2), R10.1
unnamed: J3.9 (DET_B), R25.2
unnamed: L1.1, U3.3 (SW)
unnamed: L2.1, U4.3 (SW)
unnamed: R1.2, U1.P10 (CFG_1)

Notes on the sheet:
S C H O K O
PWR3V3 COMES UP FIRST FOR MASTER SPI MODE, ECP5 DATASHEET SECTION 3.5
0.6 * (1 + (210/47)) = 3.28
MMOD has a 10K pull-up on CSPI_SS
0.6 * (1 + (100/120)) = 1.099

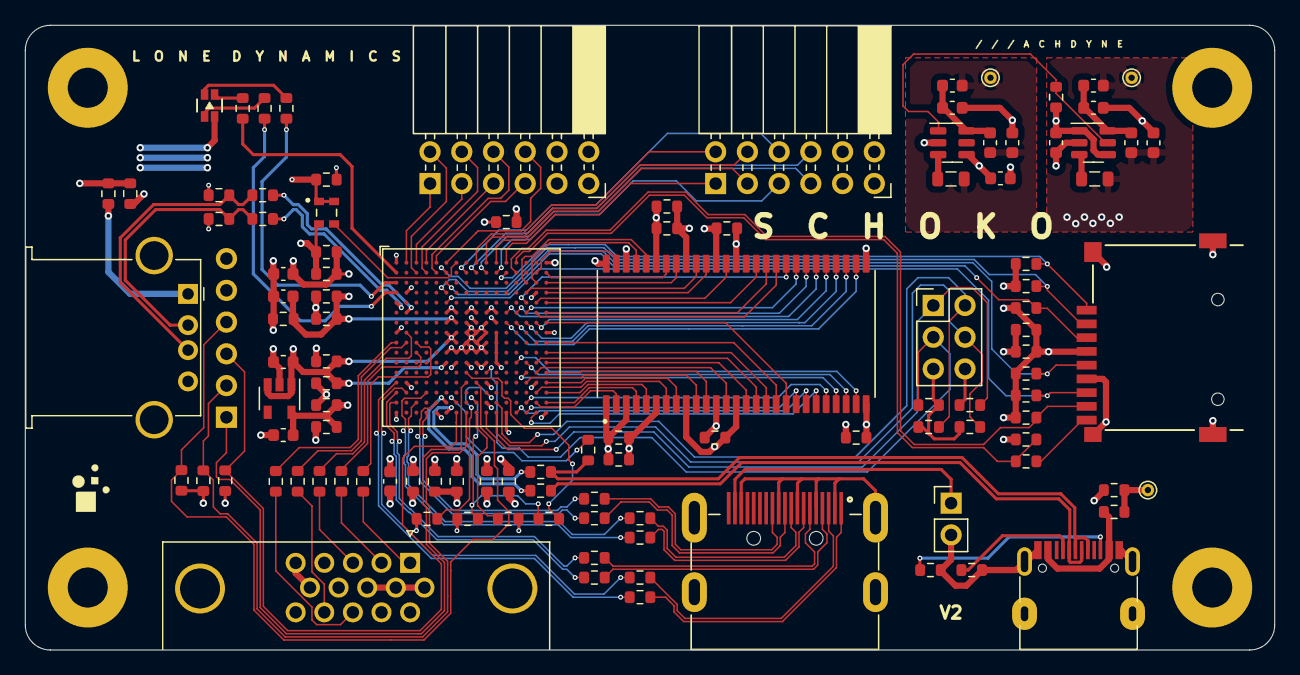
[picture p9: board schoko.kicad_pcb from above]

Board: 4 copper layers, 100.0 x 50.0 mm, 115 parts (1 on the bottom side), 131 nets.

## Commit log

2022-06-23 add schematics
2022-07-14 add case; update readme
    [schoko.scad]
2022-07-19 update readme; schoko is now in the official litex-boards repo
2022-07-26 improve fit
    [schoko.scad]
2023-06-07 add pcb
    [schoko.kicad_pcb, schoko.kicad_sch]

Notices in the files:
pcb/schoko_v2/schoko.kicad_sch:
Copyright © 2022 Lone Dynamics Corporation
